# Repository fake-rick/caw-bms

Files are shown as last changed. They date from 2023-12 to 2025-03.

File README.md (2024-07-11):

# CawBMS - 锂电池管理系统

## 🕹 简介

CawBMS 是一套基于 STM32F103 和 BQ76920 的锂电池管理系统。

所有设计资料基于 MIT 协议开源，欢迎大家复刻，可做商业用途。

**请保留 PCB、源码文件中的作者及 Logo 的相关信息。**

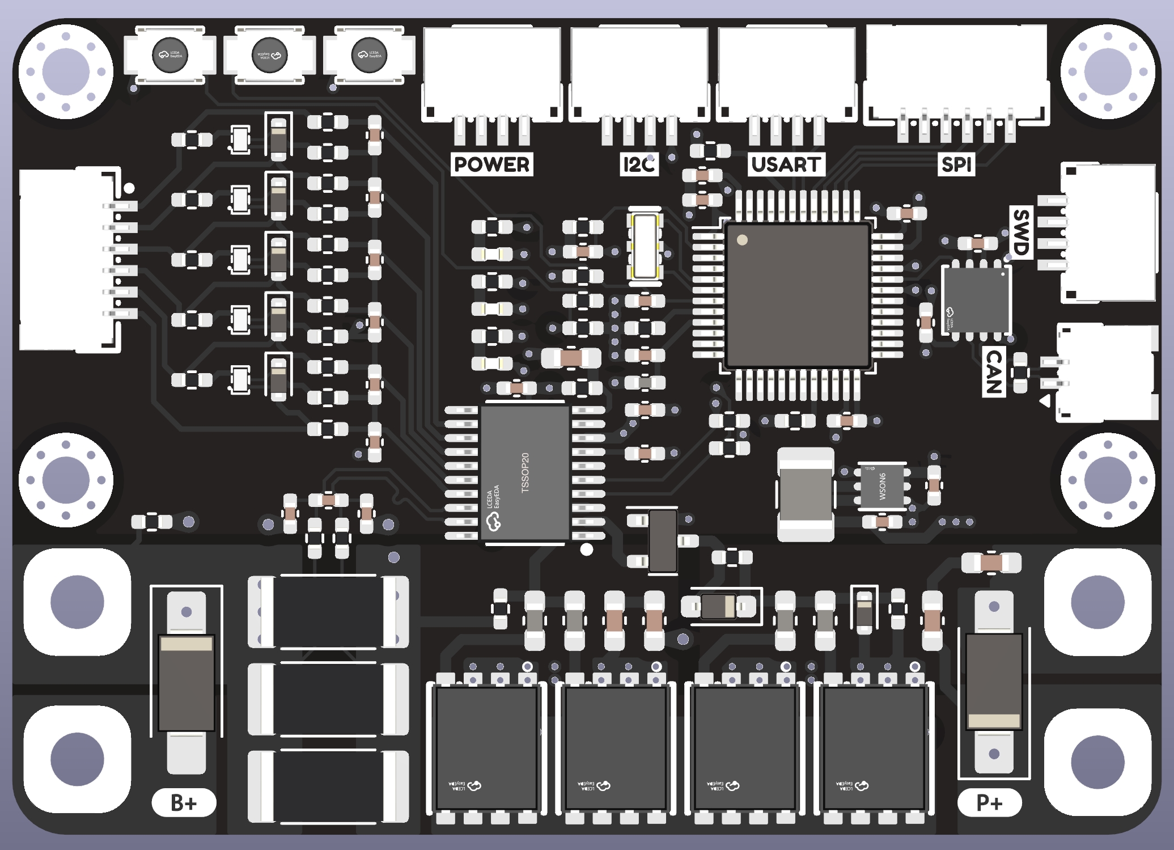
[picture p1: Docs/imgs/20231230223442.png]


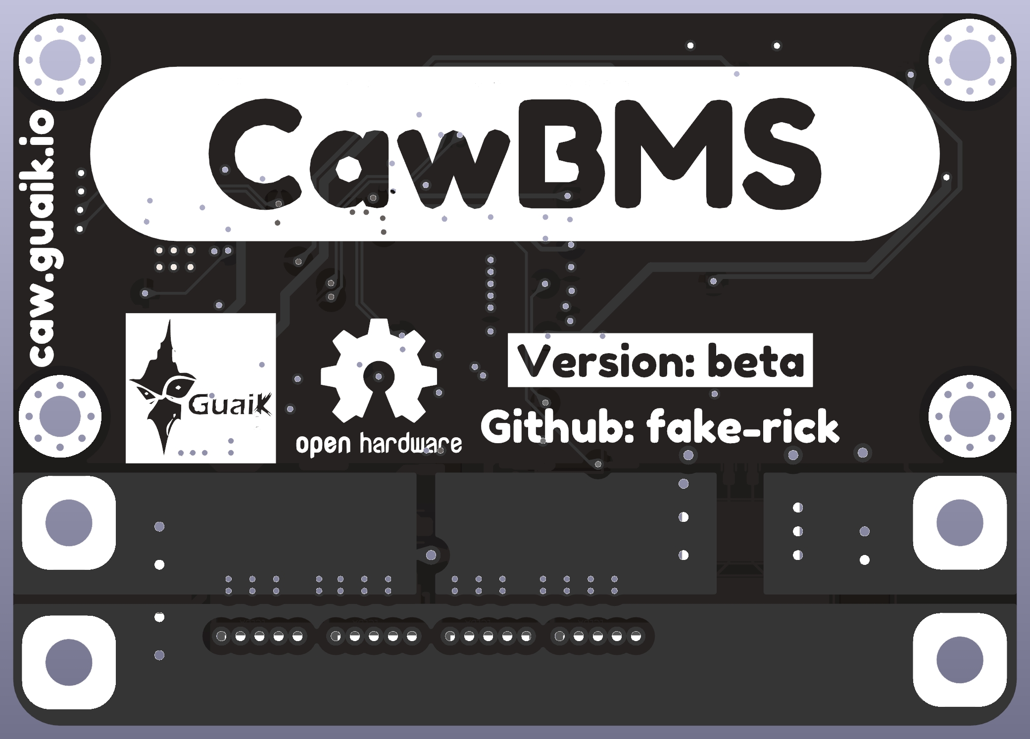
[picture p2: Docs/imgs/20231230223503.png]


## 🛠 功能

| 名称 | 开发状态 | 测试状态 | 名称 | 开发状态 | 测试状态 |
| --- | ---- | ---- | --- | ---- | ---- |
| 开机 | ✔ | ✔ | 欠压保护 | ✔ | ✔ |
| 关机 | ✔ | ✔ | 单节电压监测  | ✔ | ✔ |
| 初始化 | ✔ | ✔ | 电池组电压监测 | ✔ | ✔ |
| 短路保护 | ✔ | ❌ | 电流监测 | ✔ | ✔ |
| 过流保护 | ✔ | ✔ | SOC | ❌ | ❌ |
| 过压保护 | ✔ | ✔ | SOH | ❌ | ❌ |
| 充电被动均衡 | ✔ | ✔ | 上位机 | ❌ | ❌ |

## 📰 目录

- Docs: 项目相关文档

- GUI：上位机软件

- PCB：硬件设计

- Shell：相关外壳设计

- Firmware：固件

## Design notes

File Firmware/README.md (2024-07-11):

### 备注信息

ADCOFFSET 单位 mV
ADCGAIN 单位 uV

Cell 电压计算
V(cell) = GAIN x ADC(cell) + OFFSET

    BQ76920_Init(&afe, &hi2c1);

    HAL_GPIO_TogglePin(LED_A_GPIO_Port, LED_A_Pin);

    BQ76920_Step(&afe);
    BQ76920_UpdateBalanceCell(&afe);

    BQ76920_SYS_STAT_T state;
    BQ76920_SysStat(&afe, &state);
    CAW_LOG_DEBUG("state: %d %d %d %d %d %d %d %d", state.CC_READY, state.RSVD,
                  state.DEVICE_XREADY, state.OVRD_ALERT, state.UV, state.OV,
                  state.SCD, state.OCD);
    CAW_LOG_DEBUG("c1: %f c2: %f c3: %f c4: %f c5 %f", afe.CellVoltage[0],
                  afe.CellVoltage[1], afe.CellVoltage[2], afe.CellVoltage[3],
                  afe.CellVoltage[4]);
    CAW_LOG_DEBUG("VPack: %f, Current: %f", afe.VPack, afe.current);
    BQ76920_SYS_CTRL2_T ctl2;
    BQ76920_SysCtrl2(&afe, &ctl2);

    CAW_LOG_DEBUG("DSG: %d CHG: %d", ctl2.DSG_ON, ctl2.CHG_ON);

    BQ76920_CELLBAL1_T cellbal;
    BQ76920_CellBal1(&afe, &cellbal);
    CAW_LOG_DEBUG("cb1: %d cb2: %d cb3: %d cb4: %d cb5: %d", cellbal.CB1,
                  cellbal.CB2, cellbal.CB3, cellbal.CB4, cellbal.CB5);

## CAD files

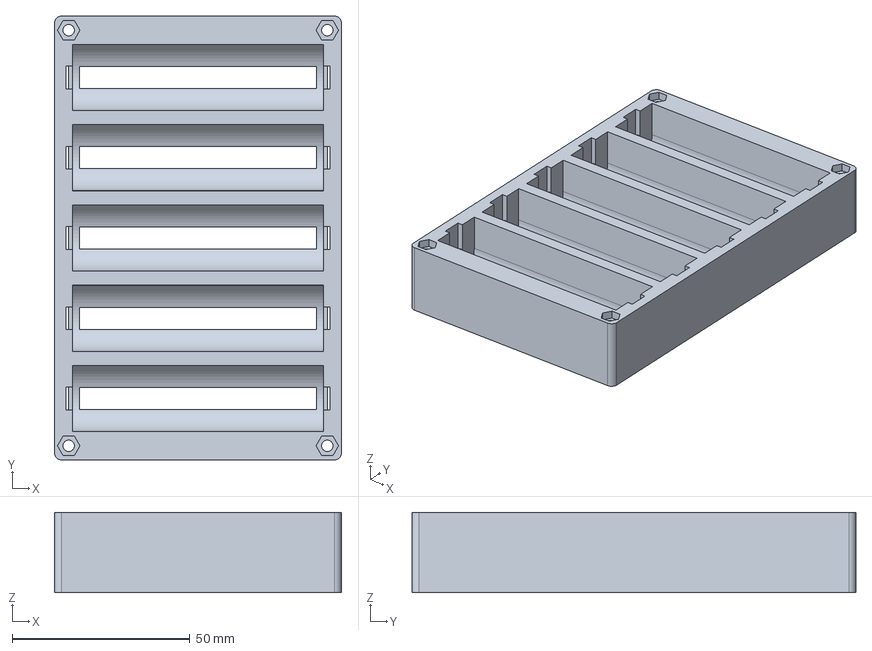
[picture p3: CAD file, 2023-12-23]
Shell/CawBMS-Shell.FCStd
80.8 x 125.0 x 22.6 mm

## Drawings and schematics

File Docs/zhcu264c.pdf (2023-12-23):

# 设计指南：TIDA-00449

# 含 10 节电池的电池组监测、平衡和综合保护、50A 放电参考设

• 专为 36V（10 节锂离子电池或磷酸铁锂电池）而设
计的电池组，可实现 50A 最大持续放电电流
• 通过控制充电或放电 FET 监测电池电压、电池组电
流、电池组温度，以及平衡电池和提供保护
• 在放电过流、放电短路、过压和欠压情况下，均能
提供硬件保护
• 板载超小尺寸、低导通电阻、低 Qg 和 Qgd 的
FemtoFET™ MOSFET，适用于高达每节电池
150mA 的无源平衡电流
• 适合装运的低静态电流、超低功耗状态
• 采用板载主机微控制器来支持实施电池电量监测

TI 设计 TIDA-00449 是一种即时可用并经过测试的硬件
平台，适用于对电动工具含 10 节串联电池的电池组执
行监控、平衡和保护。越来越多的电动工具使用高功率
密度的基于锂离子或磷酸铁锂电池的电池组，我们需要
防止这些电池组因充电或放电不当而发生爆炸。TIDA-
00449 在以持续高电流放电时，也符合电动工具电池组
的热要求。使用 2 层 PCB 实施此参考设计。

Analog Front End

该 TI 参考设计末尾的重要声明表述了授权使用、知识产权问题和其他重要的免责声明和信息。

含 10 节电池的电池组监测、平衡和综合保护、50A 放电参考设计

TIDUAR8 — http://www-s.ti.com/sc/techlit/TIDUAR8
版权 © 2015–2019, Texas Instruments Incorporated

## 1 系统 说明

## 电动工具和园艺工具的电池组较常使用的电池类型为锂离子、锂聚合物或磷酸铁锂电池。这些化学物质的体

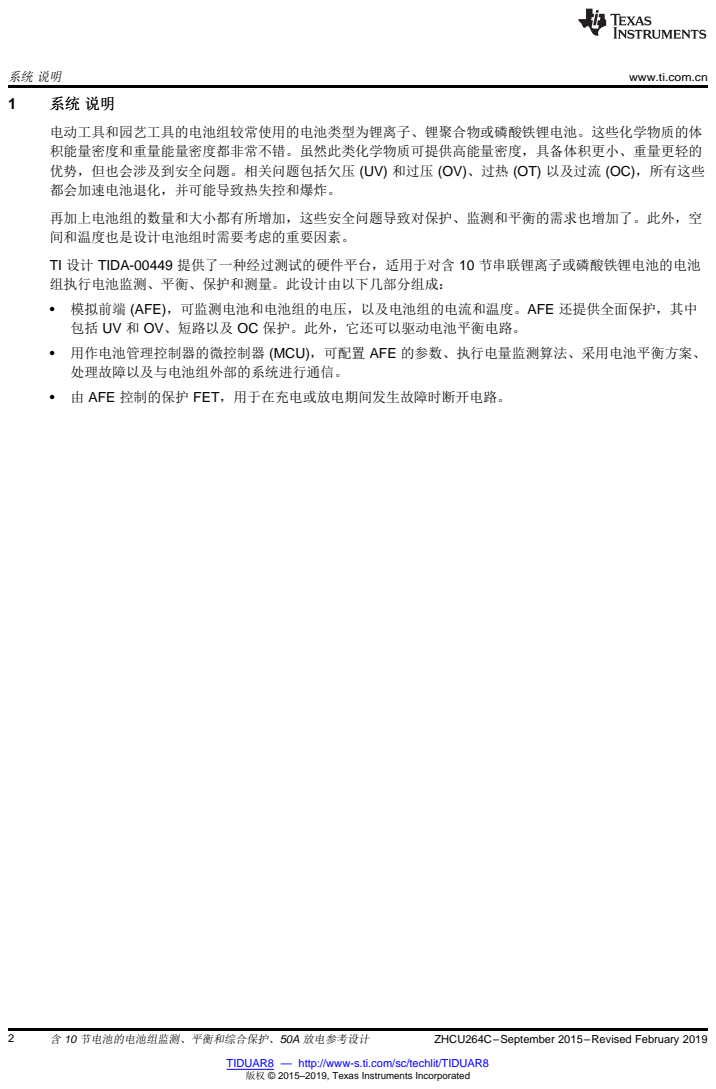
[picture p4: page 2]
www.ti.com.cn; ZHCU264C–September 2015–Revised February 2019

积能量密度和重量能量密度都非常不错。虽然此类化学物质可提供高能量密度，具备体积更小、重量更轻的
优势，但也会涉及到安全问题。相关问题包括欠压 (UV) 和过压 (OV)、过热 (OT) 以及过流 (OC)，所有这些
都会加速电池退化，并可能导致热失控和爆炸。

再加上电池组的数量和大小都有所增加，这些安全问题导致对保护、监测和平衡的需求也增加了。此外，空
间和温度也是设计电池组时需要考虑的重要因素。

TI 设计 TIDA-00449 提供了一种经过测试的硬件平台，适用于对含 10 节串联锂离子或磷酸铁锂电池的电池
组执行电池监测、平衡、保护和测量。此设计由以下几部分组成：
• 模拟前端 (AFE)，可监测电池和电池组的电压，以及电池组的电流和温度。AFE 还提供全面保护，其中
包括 UV 和 OV、短路以及 OC 保护。此外，它还可以驱动电池平衡电路。
• 用作电池管理控制器的微控制器 (MCU)，可配置 AFE 的参数、执行电量监测算法、采用电池平衡方案、
处理故障以及与电池组外部的系统进行通信。
• 由 AFE 控制的保护 FET，用于在充电或放电期间发生故障时断开电路。

## 2 设计 特性

### TIDA-00449 使用 10S3P 电池组（30-42V，12.6Ah）。

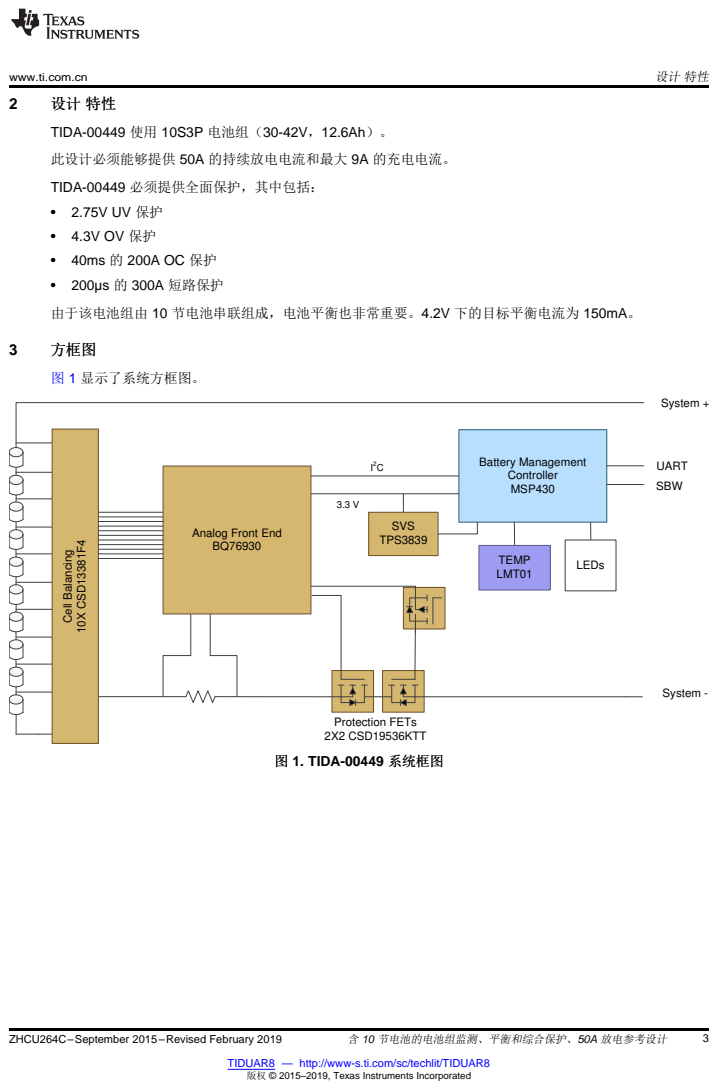
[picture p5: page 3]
LEDs; SVS TPS3839; Battery Management Controller MSP430; System +; System -; UART; SBW; Cell Balancing; 10X CSD13381F4; Protection FETs 2X2 CSD19536KTT; TEMP LMT01; www.ti.com.cn; 3 方框图; 图 1 显示了系统方框图。; 图 1. TIDA-00449 系统框图

此设计必须能够提供 50A 的持续放电电流和最大 9A 的充电电流。

TIDA-00449 必须提供全面保护，其中包括：
• 200µs 的 300A 短路保护

由于该电池组由 10 节电池串联组成，电池平衡也非常重要。4.2V 下的目标平衡电流为 150mA。

Analog Front End

SENSE _ OCD _MAX

100 mV R | 0.5 m
200 A
= | = | W SENSE _ SCD _MAX
200 mV R | 0.667 m
300 A
= | = | W

THRESHOLD
SENSE
LIM

V
R
I

=

电路设计和组件选择 | www.ti.com.cn

## 4 电路设计和组件选择

## 4.1 AFE

### 4.1.1 器件选择

## bq769x0 系列的强大 AFE 设备可用作下一代高功率系统（如电动工具）的完整电池组监测和保护解决方案 的一部分。bq769x0 在设计时充分考虑了低功耗要求，不仅可通过启用/禁用集成电路 (IC) 中的子块来控制 整个芯片的电流消耗，而且还可以利用运输模式将电池组轻松切换至超低功耗状态。

## bq76930 最高支持 10 节串联电池或典型的 36V 电池组。该 AFE 可以测量各种电池化学物质，包括锂离 子、磷酸铁锂等。通过 I

## 2C，主机控制器可以使用 bq76930 来执行多种电池组管理功能，例如监测（电池电 压、电池组电流、电池组温度）、保护（控制充电/放电 FET）以及平衡功能。集成式 ADC 可实现对关键系 统参数的纯数字读取，这些参数的校准在 TI 制造过程中进行处理。

### 4.1.2 电流感测

## 在设计电池组监测、平衡和保护电路时，首先要做的工作之一是选择传感电阻器。为此，请考虑短路电流限 制 (SCD) 和过流限制 (OCD)，以及 AFE 使用的电压阈值设置。请注意，在电池管理控制器中可以进一步实 施其他电流限制阈值，以实现更详尽的保护方案（请参见节 4.2.3.1）。

### 此设计的目标是：300A 左右的 SCD 持续 200μs，200A 左右的 OCD 持续 40ms。您可以在 bq76930 产品

说明书 (SLUSBK2) (http://www.ti.com/lit/pdf/SLUSBK2) 的第 36 页和 37 页查看电压阈值设置。SCD 和 OCD 的电压阈值最大值分别为 200mV

## 和 100mV。根据欧姆定律，SCD 的传感电阻器最大值为 0.67mΩ，OCD 的传感电阻器最大值为 0.5mΩ， 如公式 2 和公式 3 中所示。

(1)

因此，

(2)

(3)

## 所选的 RSENSE 等于 0.5mΩ。

## 为了采用 300A 的 0.5mΩ 传感电阻器，电压阈值现已经过重新计算。重复利用公式 2 可为 SCD 提供

150mV 的电压阈值。bq76930 产品说明书 (SLUSBK2) (http://www.ti.com/lit/pdf/SLUSBK2) 第 36 页的表格中未列出 150mV，但列出了

### 155mV；因此，采用 155mV 为 SCD 提供 310A 的电流。

## 此应用的最大持续电流为 50A，这意味着使用 0.5mΩ 的传感电阻器时，会消耗 1.25W 功率。

## 考虑到所有这些因素（包括功耗方面的一些优势），可以并联使用三个 1.5mΩ 的 2512 1% 2W 电阻器装 置。使用 SCD 和 OCD 比较器持续监测传感电阻器的电压，从而提供保护。该电压还会被馈送至 16 位集成 式 ADC（通常称为库仑计数器 (CC)），该 ADC 会测量电流传感电阻器上累积的电荷。

www.ti.com.cn | 电路设计和组件选择

### 4.1.3 保护 FET

## 现在，我们已选择好传感电阻器，下一步是设计保护 FET。

## 这些 FET 用于在发生故障时断开电路。表 1 显示了放电 FET (DSG) 和充电 FET (CHG) 何时设断开状态。

## 对于这两个 FET，采用单独控制的方式，即使发生某种故障，也可以安全地使用电池组。例如，如果电池组 已完全放电，则会触发 UV 故障，从而断开 DSG FET，防止放电电流进一步流动。与此同时，CHG FET 保 持闭合状态，允许所施加的充电电流流动。

## 表 1. CHG 和 DSG 对不同事件的响应

事件 | CHG FET 断开 | DSG FET 断开
OV 故障 | 是 | —
UV 故障 | — | 是
OCD 故障 | — | 是
SCD 故障 | — | 是
警报覆盖 | 是 | 是
已设置 DEVICE_XREADY | 是 | 是
从正常模式进入运输模式 | 是 | 是

## 在不需要保护 FET 的情况下，TIDA-00449 为用户提供了两个焊盘以绕过保护 FET。7.4 节 中提供了更多详 细信息。

### 4.1.3.1 FET 选择

## 要选择 FET，请考虑以下四个主要参数：电压、电流、热性能和 FET 的开关时间。

## FET 的额定电压必须高于每节串联电池约 5V 的直流电压，以及每节串联电池的 10V 瞬态电压。在本设计 中，装置使用了 10 节电池串联，这意味着 FET（Q13、Q14、Q15 和 Q16）的额定电压应高于 50V 直流 电压和 100V 瞬态电压。

### TIDA-00449 的电流要求如下：75A 持续电流，300A 电流持续 400μs，200A 瞬态电流持续 40ms。

## 在热性能方面，要优先考虑使用尽可能低的 RDSON 值，以便最大程度地减少这些 FET 的功耗。此外，封装 也是一项关键因素，因为它应该能够承受热损耗并有效地消散 PCB 或散热器的热损耗。

## 最后，断开和闭合 FET 所需的时间也至关重要。这主要受 BQ76930 AFE 中栅极驱动器的强度和 FET 的栅 极电荷的影响（请参见节 4.1.3.2，了解更多详细信息）。

## 本设计将所有这些参数均考虑在内，并联使用了两个 CSD19536KTT。CSD19536KTT 是一个 100V、

### 2mΩ、超低 Qg 和 Qgd 的 D

### 2PAK (TO-263) NexFET™ 功率 MOSFET。

电路设计和组件选择 | www.ti.com.cn

### 4.1.3.2 FET 驱动器
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

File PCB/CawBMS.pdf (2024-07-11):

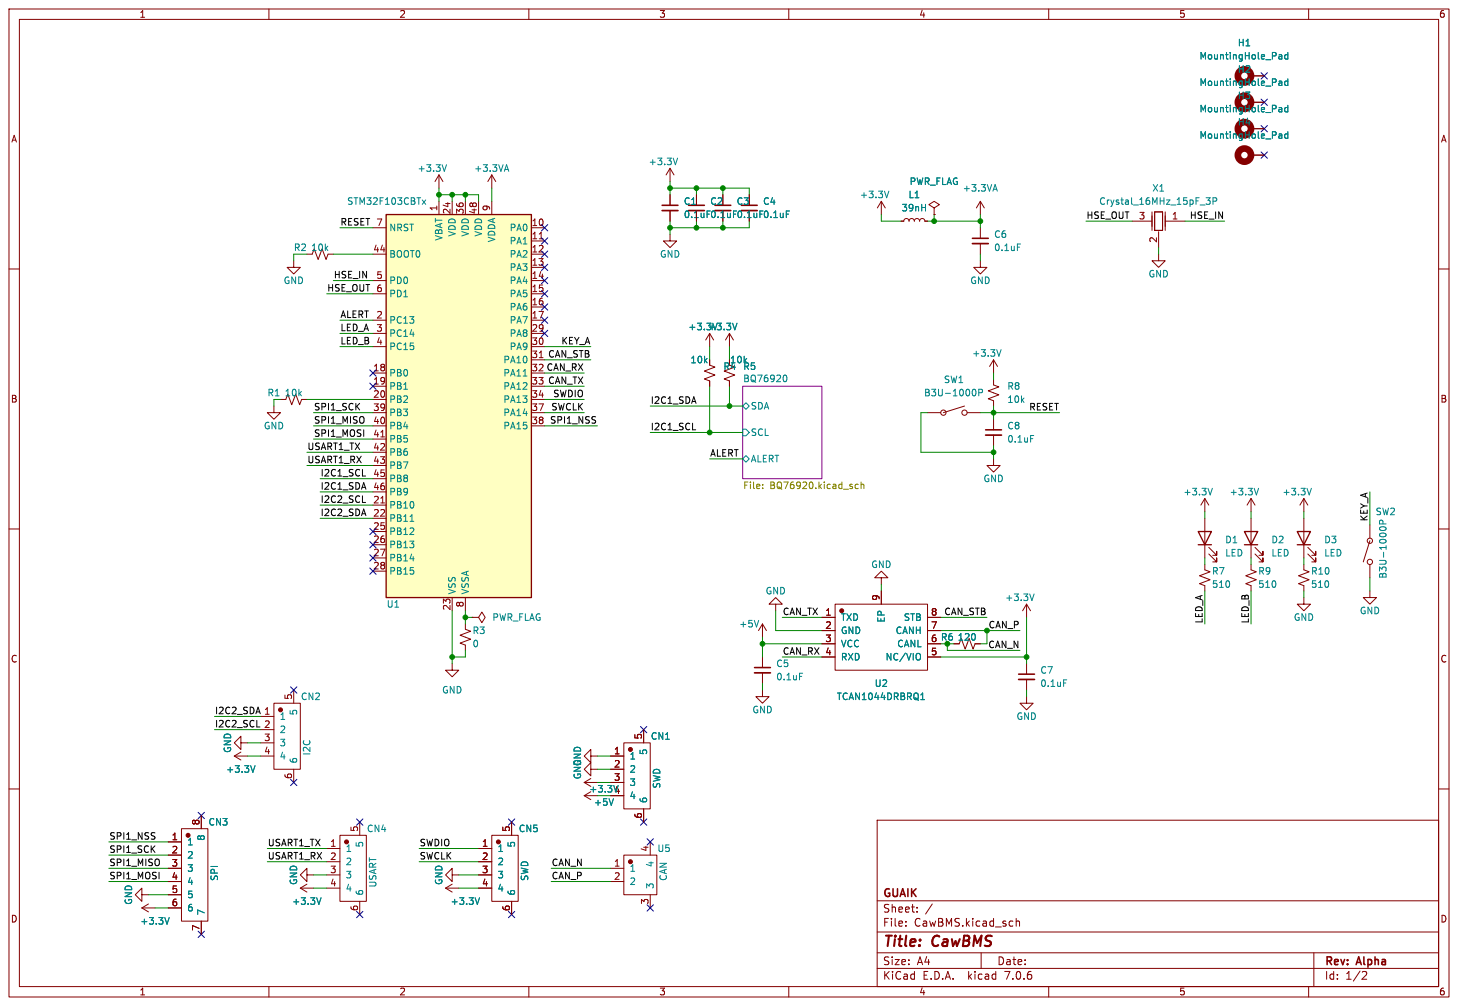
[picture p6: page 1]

1 PA0 10 PA1 11 PA2 12 PA3 13 PA4 14 PA5 15 PA6 16 PA7 17 PB0 18 PB1 19 PC13 2 PB2 20 PB10 21 PB11 22 VSS 23 VDD 24 PB12 25 PB13 26 PB14 27 PB15 28 PA8 29 PC14 3 PA9 30 PA10 31 PA11 32 PA12 33 PA13 34 VDD 36 PA14 37 PA15 38 PB3 39 PC15 4 PB4 40 PB5 41 PB6 42 PB7 43 BOOT0 44 PB8 45 PB9 46 VDD 48 PD0 5 PD1 6 NRST 7 VSSA

File: CawBMS.kicad_sch Sheet: / GUAIK

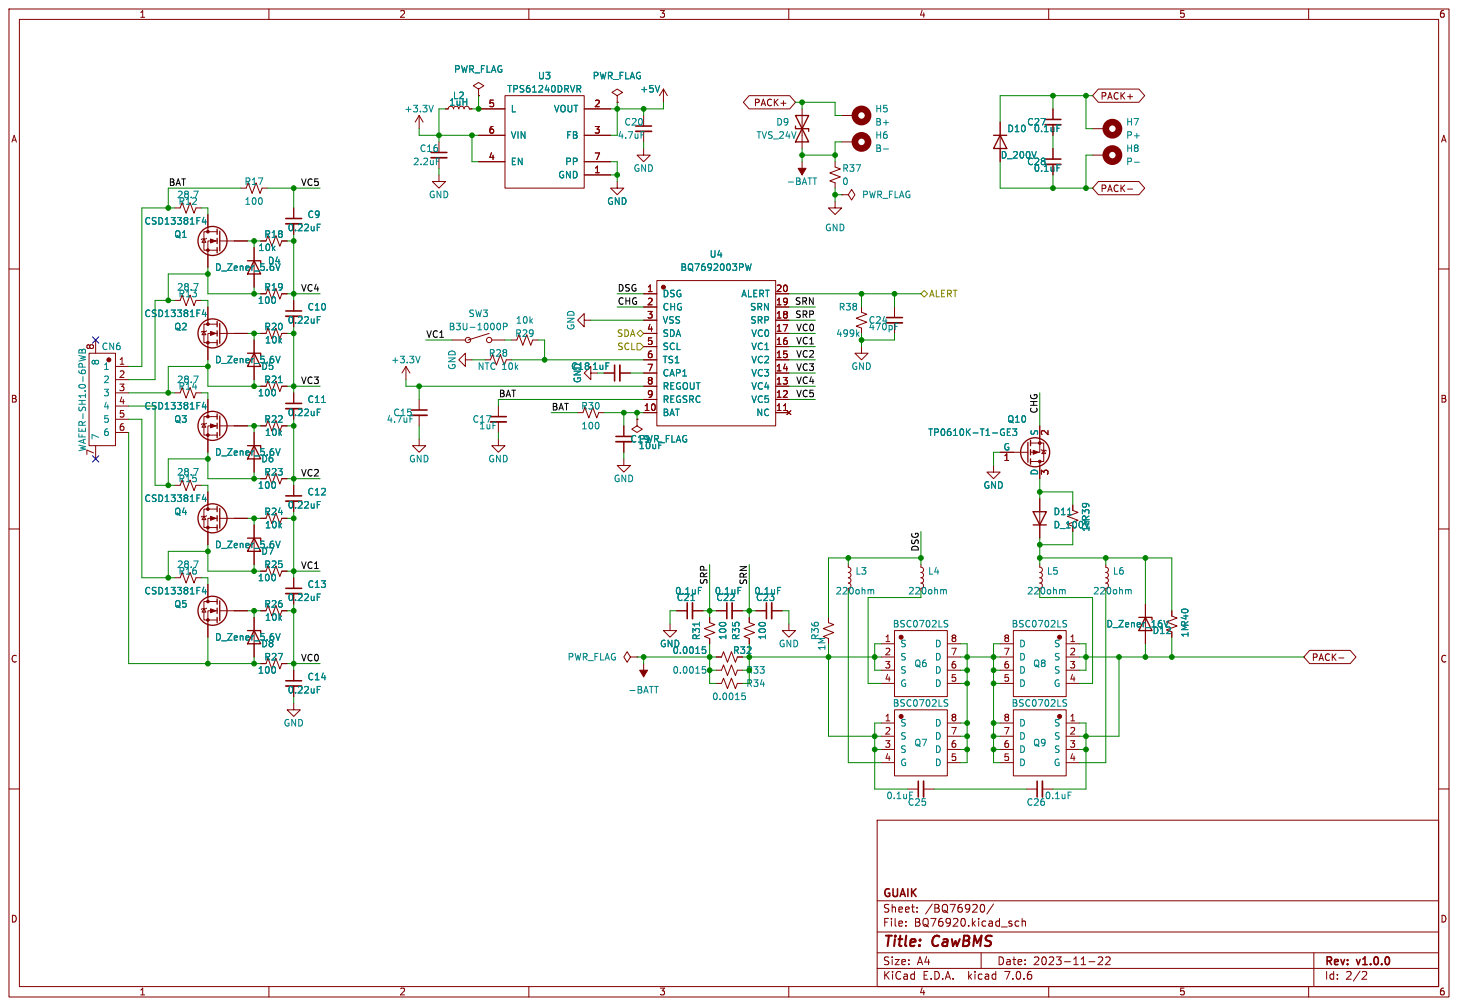
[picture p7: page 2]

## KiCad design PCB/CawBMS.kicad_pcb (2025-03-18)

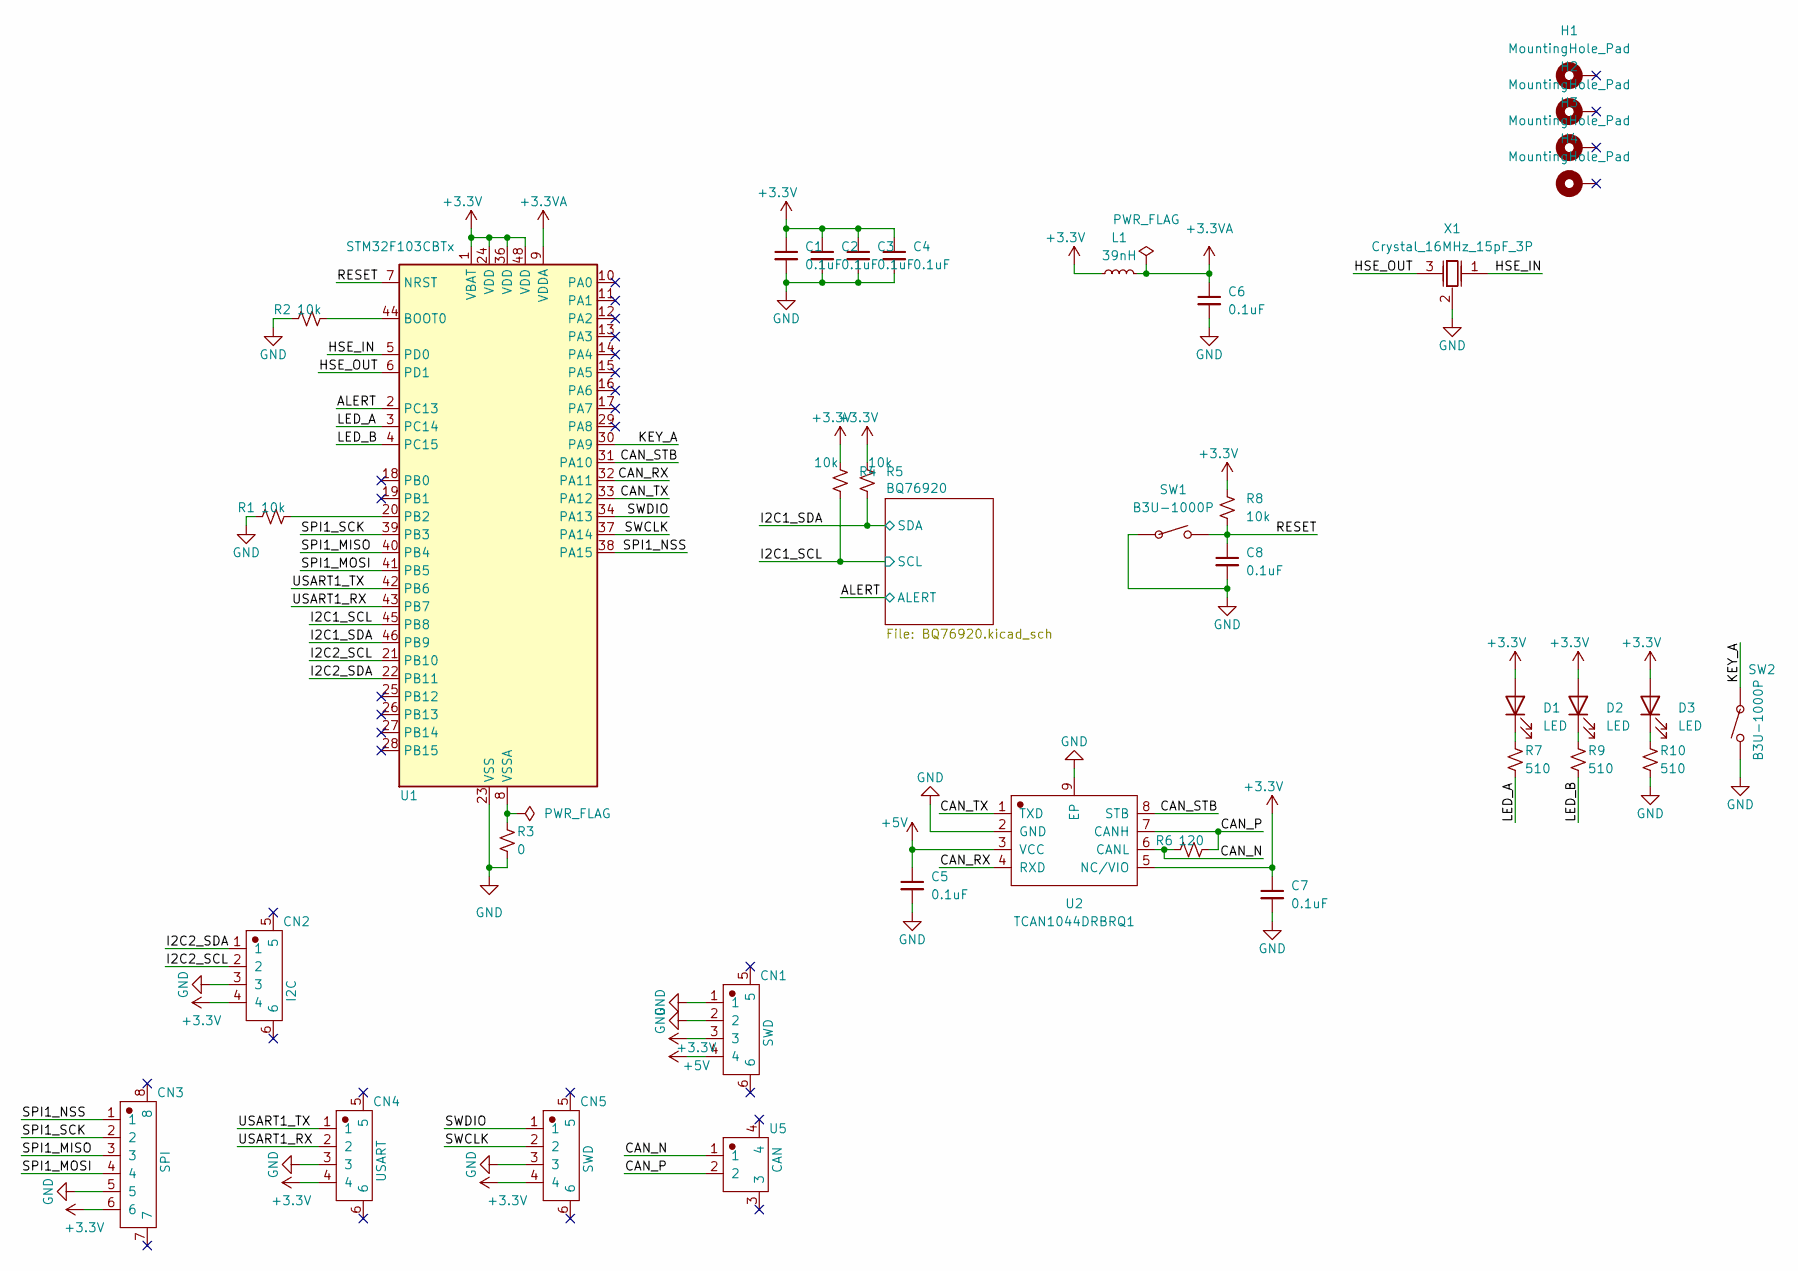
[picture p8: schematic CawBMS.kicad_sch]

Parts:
C1, C2, C3, C4, C5, C6, C7, C8: 0.1uF; C_0402_1005Metric_Pad0.74x0.62mm_HandSolder
CN1, CN5: SWD; CONN-SMD_4P-P1.00_WAFER-SH1.0-4PWB
CN2: I2C; CONN-SMD_4P-P1.00_WAFER-SH1.0-4PWB
CN3: SPI; CONN-SMD_6P-P1.00_XUNPU_WAFER-SH1.0-6PWB
CN4: USART; CONN-SMD_4P-P1.00_WAFER-SH1.0-4PWB
D1, D2, D3: LED; LED_0402_1005Metric_Pad0.77x0.64mm_HandSolder
H1, H2, H3, H4: MountingHole_Pad; MountingHole_2.2mm_M2_Pad_Via
L1: 39nH; L_0402_1005Metric_Pad0.77x0.64mm_HandSolder
R1, R2, R4, R5, R8: 10k; R_0402_1005Metric_Pad0.72x0.64mm_HandSolder
R3: 0; R_0402_1005Metric_Pad0.72x0.64mm_HandSolder
R6: 120; R_0402_1005Metric_Pad0.72x0.64mm_HandSolder
R7, R9, R10: 510; R_0402_1005Metric_Pad0.72x0.64mm_HandSolder
SW1, SW2: B3U-1000P; JLC Part Number C231329
U1: STM32F103CBTx; LQFP-48_7x7mm_P0.5mm
U2: TCAN1044DRBRQ1; TCAN1044DRBRQ1_DFN-8_L3.0-W3.0-P0.65-TL-EP2.4
U5: CAN; CONN-SMD_2P-P1.00_XUNPU_WAFER-SH1.0-2PWB
X1: Crystal_16MHz_15pF_3P; Crystal_SMD3213-3P; JLC Part Number C341521

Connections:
+3.3V: C1.1, C2.1, C3.1, C4.1, C7.1, CN1.3, CN2.4, CN3.6, CN4.4, CN5.4, D1.2 (A), D2.2 (A), D3.2 (A), L1.1, R4.1, R5.1, R8.1, U1.1 (VBAT), U1.24 (VDD), U1.36 (VDD), U1.48 (VDD), U2.5 (NC/VIO); also elsewhere on the board
+3.3VA: C6.1, L1.2, U1.9 (VDDA)
+5V: C5.1, CN1.4, U2.3 (VCC); also elsewhere on the board
/ALERT: U1.2 (PC13); also elsewhere on the board
/CAN_N: R6.1, U2.6 (CANL), U5.1
/CAN_P: R6.2, U2.7 (CANH), U5.2
/CAN_RX: U1.32 (PA11), U2.4 (RXD)
/CAN_STB: U1.31 (PA10), U2.8 (STB)
/CAN_TX: U1.33 (PA12), U2.1 (TXD)
/HSE_IN: U1.5 (PD0), X1.1 (OSC1)
/HSE_OUT: U1.6 (PD1), X1.3 (OSC2)
/I2C1_SCL: R4.2, U1.45 (PB8); also elsewhere on the board
/I2C1_SDA: R5.2, U1.46 (PB9); also elsewhere on the board
/I2C2_SCL: CN2.2, U1.21 (PB10)
/I2C2_SDA: CN2.1, U1.22 (PB11)
/KEY_A: SW2.1, U1.30 (PA9)
/LED_A: R7.2, U1.3 (PC14)
/LED_B: R9.2, U1.4 (PC15)
/RESET: C8.1, R8.2, SW1.2, U1.7 (NRST)
/SPI1_MISO: CN3.3, U1.40 (PB4)
/SPI1_MOSI: CN3.4, U1.41 (PB5)
/SPI1_NSS: CN3.1, U1.38 (PA15)
/SPI1_SCK: CN3.2, U1.39 (PB3)
/SWCLK: CN5.2, U1.37 (PA14)
/SWDIO: CN5.1, U1.34 (PA13)
/USART1_RX: CN4.2, U1.43 (PB7)
/USART1_TX: CN4.1, U1.42 (PB6)
GND: C1.2, C2.2, C3.2, C4.2, C5.2, C6.2, C7.2, C8.2, CN1.1, CN1.2, CN2.3, CN3.5, CN4.3, CN5.3, R1.1, R2.1, R3.2, R10.2, SW1.1, SW2.2, U1.23 (VSS), U1.35 (VSS), U1.47 (VSS), U2.2 (GND), U2.9 (EP), X1.2 (GND); also elsewhere on the board
unnamed: D1.1 (K), R7.1
unnamed: D2.1 (K), R9.1
unnamed: D3.1 (K), R10.1
unnamed: R2.2, U1.44 (BOOT0)
unnamed: R1.2, U1.20 (PB2)
unnamed: R3.1, U1.8 (VSSA)

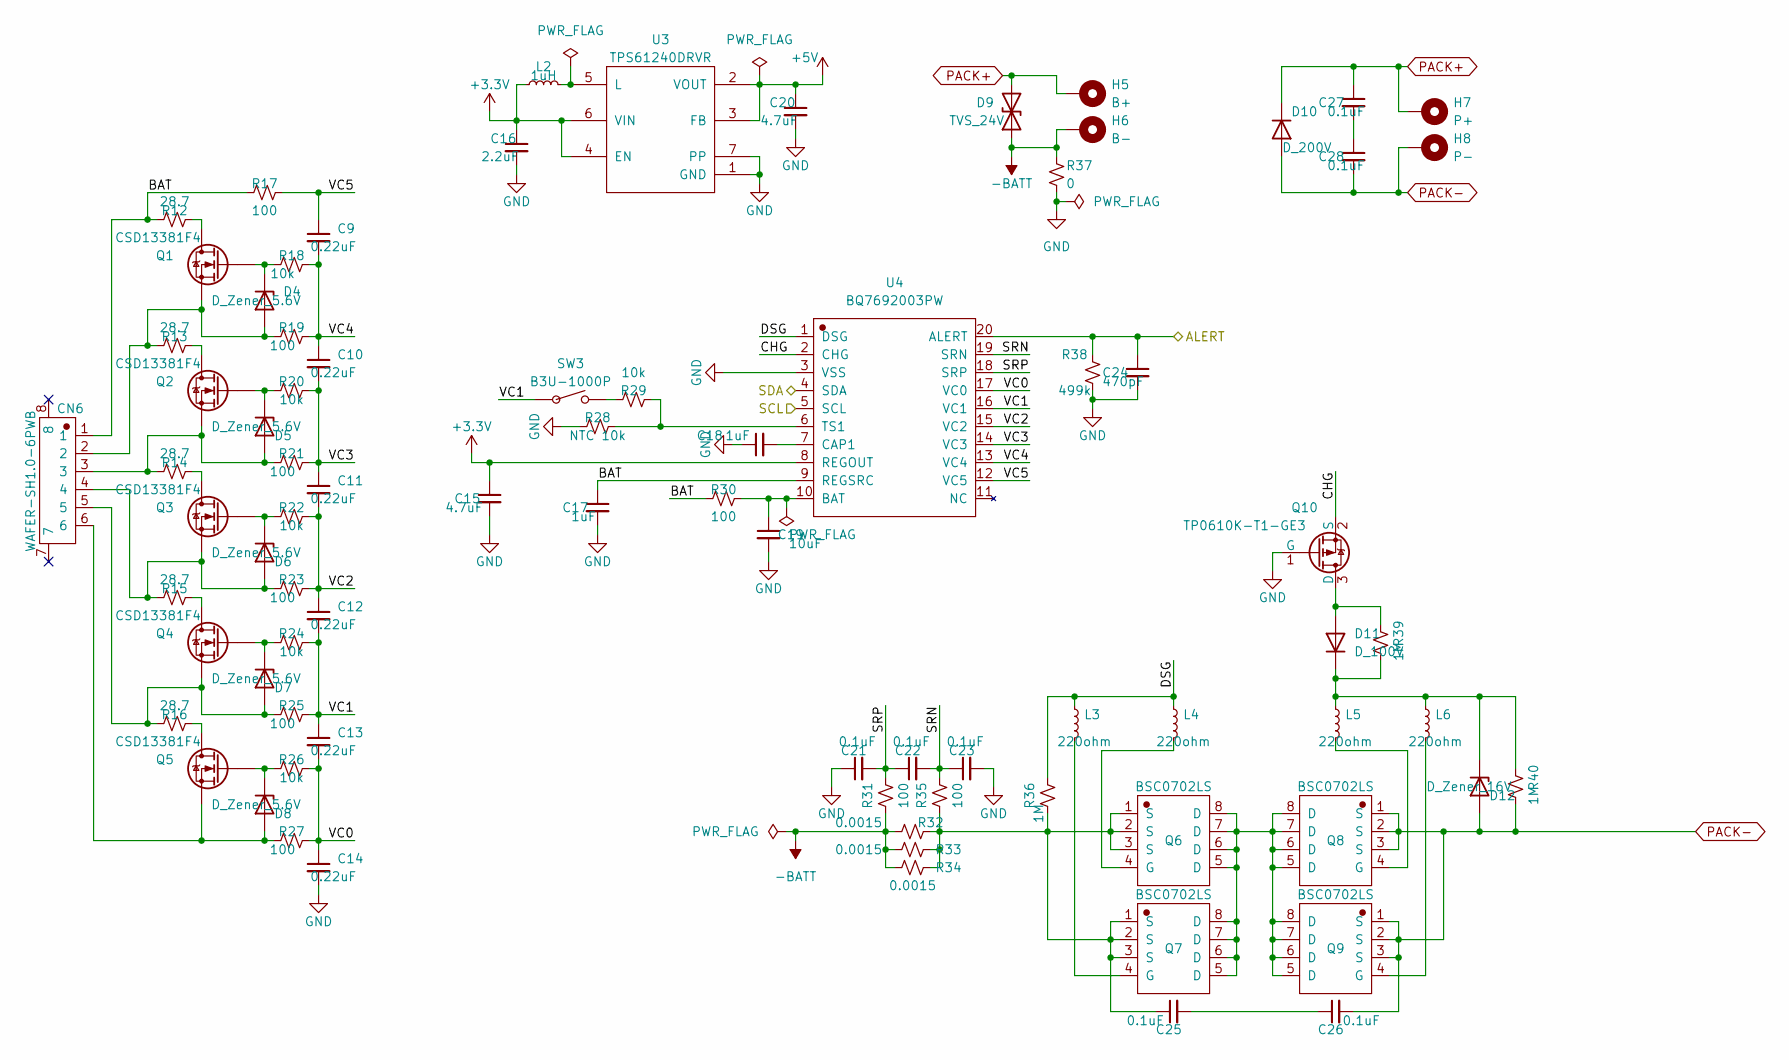
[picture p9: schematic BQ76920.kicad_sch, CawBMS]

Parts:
C9, C10, C11, C12, C13, C14: 0.22uF; C_0402_1005Metric_Pad0.74x0.62mm_HandSolder
C15, C20: 4.7uF; C_0402_1005Metric_Pad0.74x0.62mm_HandSolder
C16: 2.2uF; C_0402_1005Metric_Pad0.74x0.62mm_HandSolder
C17, C18: 1uF; C_0402_1005Metric_Pad0.74x0.62mm_HandSolder
C19: 10uF; C_0603_1608Metric_Pad1.08x0.95mm_HandSolder
C21, C22, C23: 0.1uF; C_0402_1005Metric_Pad0.74x0.62mm_HandSolder
C24: 470pF; C_0402_1005Metric_Pad0.74x0.62mm_HandSolder
C25, C26, C27, C28: 0.1uF; C_0603_1608Metric_Pad1.08x0.95mm_HandSolder
CN6: WAFER-SH1.0-6PWB; CONN-SMD_6P-P1.00_XUNPU_WAFER-SH1.0-6PWB
D4, D5, D6, D7, D8: D_Zener_5.6V; D_SOD-523
D9: TVS_24V; D_SMA_Handsoldering
D10: D_200V; D_SMA_Handsoldering
D11: D_100V; D_SOD-323_HandSoldering
D12: D_Zener_16V; D_SOD-523
H5: B+; POWER_PAD
H6: B-; POWER_PAD
H7: P+; POWER_PAD
H8: P-; POWER_PAD
L2: 1uH; L_1210_3225Metric_Pad1.42x2.65mm_HandSolder
L3, L4, L5, L6: 220ohm; L_0603_1608Metric_Pad1.05x0.95mm_HandSolder
Q1, Q2, Q3, Q4, Q5: CSD13381F4; CSD13381F4_PICOSTAR-3_L1.0-W0.6-P0.40-S0.65-BL-1
Q6, Q7, Q8, Q9: BSC0702LS; BSC0702LS_PG-TDSON-8_L5.0-W6.0-P1.27-BL-EP
Q10: TP0610K-T1-GE3; SOT-23
R12, R13, R14, R15, R16: 28.7; R_0402_1005Metric_Pad0.72x0.64mm_HandSolder
R17, R19, R21, R23, R25, R27, R30, R31, R35: 100; R_0402_1005Metric_Pad0.72x0.64mm_HandSolder
R18, R20, R22, R24, R26, R29: 10k; R_0402_1005Metric_Pad0.72x0.64mm_HandSolder
R28: NTC 10k; R_0402_1005Metric_Pad0.72x0.64mm_HandSolder
R32, R33, R34: 0.0015; R_2512_6332Metric_Pad1.40x3.35mm_HandSolder
R36, R39, R40: 1M; R_0402_1005Metric_Pad0.72x0.64mm_HandSolder
R37: 0; R_0402_1005Metric_Pad0.72x0.64mm_HandSolder
R38: 499k; R_0402_1005Metric_Pad0.72x0.64mm_HandSolder
SW3: B3U-1000P; JLC Part Number C231329
U3: TPS61240DRVR; TPS61240DRVR_WSON-6_L2.0-W2.0-P0.65-TL-EP
U4: BQ7692003PW; BQ7692003PW_TSSOP-20_L6.5-W4.4-P0.65-LS6.4-BL

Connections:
+3.3V: C15.1, C16.1, L2.1, U3.4 (EN), U3.6 (VIN), U4.8 (REGOUT); also elsewhere on the board
+5V: C20.1, U3.2 (VOUT), U3.3 (FB); also elsewhere on the board
-BATT: D9.1 (A1), H6.1, R31.1, R32.1, R33.1, R34.1, R37.1
/ALERT: C24.1, R38.2, U4.20 (ALERT); also elsewhere on the board
/BQ76920/BAT: C17.1, CN6.1, R12.1, R17.1, R30.1, U4.9 (REGSRC)
/BQ76920/CHG: Q10.2 (S), U4.2 (CHG)
/BQ76920/DSG: L3.1, L4.1, R36.2, U4.1 (DSG)
/BQ76920/SRN: C22.2, C23.1, R35.2, U4.19 (SRN)
/BQ76920/SRP: C21.2, C22.1, R31.2, U4.18 (SRP)
/BQ76920/VC0: C13.2, C14.1, R26.2, R27.2, U4.17 (VC0)
/BQ76920/VC1: C12.2, C13.1, R24.2, R25.2, SW3.1, U4.16 (VC1)
/BQ76920/VC2: C11.2, C12.1, R22.2, R23.2, U4.15 (VC2)
/BQ76920/VC3: C10.2, C11.1, R20.2, R21.2, U4.14 (VC3)
/BQ76920/VC4: C9.2, C10.1, R18.2, R19.2, U4.13 (VC4)
/BQ76920/VC5: C9.1, R17.2, U4.12 (VC5)
/I2C1_SCL: U4.5 (SCL); also elsewhere on the board
/I2C1_SDA: U4.4 (SDA); also elsewhere on the board
GND: C14.2, C15.2, C16.2, C17.2, C18.1, C19.2, C20.2, C21.1, C23.2, C24.2, Q10.1 (G), R28.1, R37.2, R38.1, U3.1 (GND), U3.7 (PP), U4.3 (VSS); also elsewhere on the board
unnamed: C25.1, Q6.1 (S), Q6.2 (S), Q6.3 (S), Q7.1 (S), Q7.2 (S), Q7.3 (S), R32.2, R33.2, R34.2, R35.1, R36.1
unnamed: C25.2, C26.1
unnamed: C27.2, C28.1
unnamed: CN6.2, D4.2 (A), Q1.2 (S), R13.1, R19.1
unnamed: D4.1 (K), Q1.1 (G), R18.1
unnamed: CN6.3, D5.2 (A), Q2.2 (S), R14.1, R21.1
unnamed: D5.1 (K), Q2.1 (G), R20.1
unnamed: CN6.4, D6.2 (A), Q3.2 (S), R15.1, R23.1
unnamed: D6.1 (K), Q3.1 (G), R22.1
unnamed: CN6.5, D7.2 (A), Q4.2 (S), R16.1, R25.1
unnamed: D7.1 (K), Q4.1 (G), R24.1
unnamed: CN6.6, D8.2 (A), Q5.2 (S), R27.1
unnamed: D8.1 (K), Q5.1 (G), R26.1
unnamed: D11.2 (A), Q10.3 (D), R39.2
unnamed: D11.1 (K), D12.1 (K), L5.1, L6.1, R39.1, R40.2
unnamed: Q1.3 (D), R12.2
unnamed: Q2.3 (D), R13.2
unnamed: Q3.3 (D), R14.2
unnamed: Q4.3 (D), R15.2
unnamed: Q5.3 (D), R16.2
unnamed: Q6.5 (D), Q6.6 (D), Q6.7 (D), Q6.8 (D), Q7.5 (D), Q7.6 (D), Q7.7 (D), Q7.8 (D), Q8.5 (D), Q8.6 (D), Q8.7 (D), Q8.8 (D), Q9.5 (D), Q9.6 (D), Q9.7 (D), Q9.8 (D)
unnamed: L4.2, Q6.4 (G)
unnamed: L3.2, Q7.4 (G)
unnamed: L5.2, Q8.4 (G)
unnamed: L6.2, Q9.4 (G)
unnamed: R29.1, SW3.2
unnamed: L2.2, U3.5 (L)
unnamed: C19.1, R30.2, U4.10 (BAT)
unnamed: C18.2, U4.7 (CAP1)
unnamed: R28.2, R29.2, U4.6 (TS1)
PACK+: C27.1, D9.2 (A2), D10.1 (K), H5.1, H7.1
PACK-: C26.2, C28.2, D10.2 (A), D12.2 (A), H8.1, Q8.1 (S), Q8.2 (S), Q8.3 (S), Q9.1 (S), Q9.2 (S), Q9.3 (S), R40.1

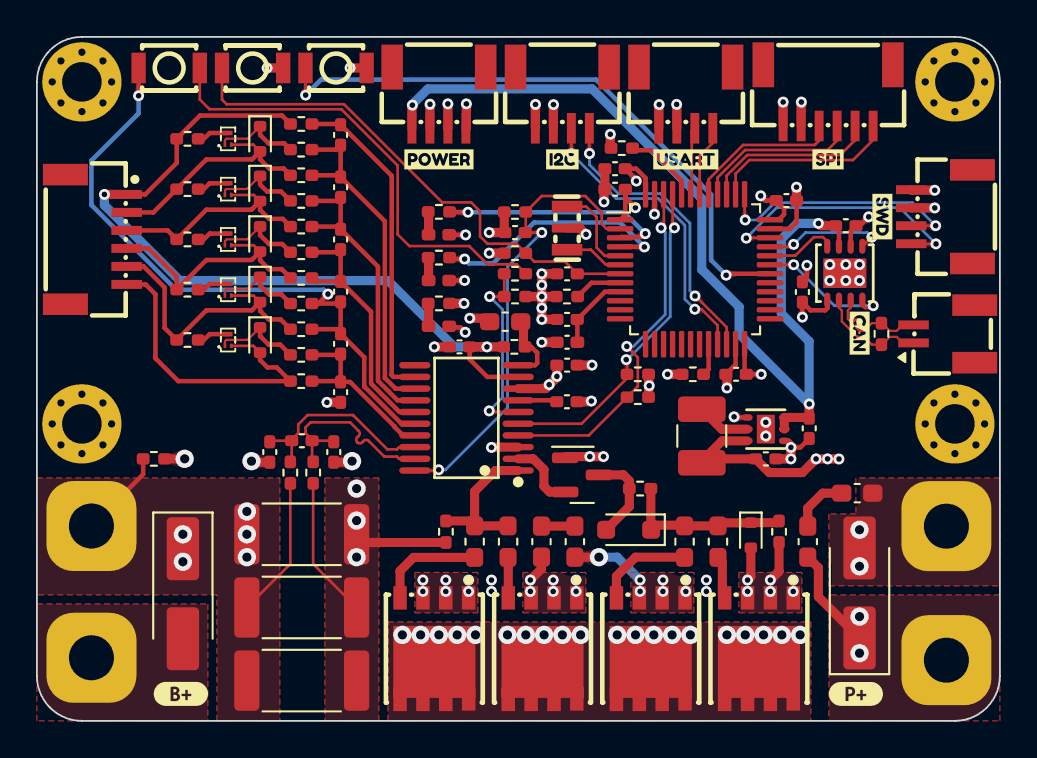
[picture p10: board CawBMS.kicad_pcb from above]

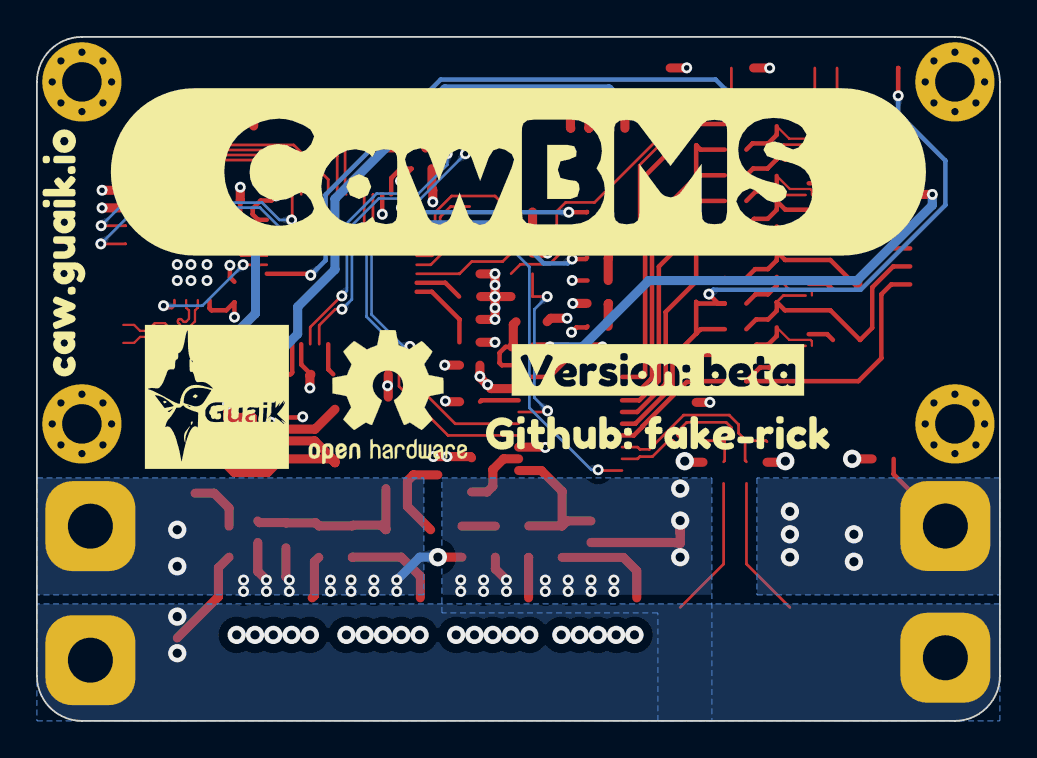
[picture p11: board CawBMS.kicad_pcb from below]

Board: 4 copper layers, 53.5 x 38.0 mm, 130 parts (4 on the bottom side), 78 nets.

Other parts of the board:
kibuzzard-658FE662: G***; kibuzzard-658FE662
kibuzzard-658FE679: G***; kibuzzard-658FE679
kibuzzard-6577EBAB: G***; kibuzzard-6577EBAB
kibuzzard-6577EBC9: G***; kibuzzard-6577EBC9
kibuzzard-6577EC0F: G***; kibuzzard-6577EC0F
kibuzzard-6577EC47: G***; kibuzzard-6577EC47
kibuzzard-6577F8B5: G***; kibuzzard-6577F8B5
kibuzzard-6577F12B: G***; kibuzzard-6577F12B
kibuzzard-6577F182: G***; kibuzzard-6577F182
kibuzzard-6582907D: G***; kibuzzard-6582907D
kibuzzard-65829086: G***; kibuzzard-65829086
kibuzzard-65902364: G***; kibuzzard-65902364

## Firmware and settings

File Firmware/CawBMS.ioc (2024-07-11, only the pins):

Mcu.UserName=STM32F103CBTx
PA10.GPIO_Label=CAN_STB
PA10.Signal=GPIO_Output
PA11.Signal=CAN_RX
PA12.Signal=CAN_TX
PA13.Signal=SYS_JTMS-SWDIO
PA14.Signal=SYS_JTCK-SWCLK
PA15.GPIO_Label=SPI1_NSS
PA15.Signal=GPIO_Output
PA9.GPIO_Label=KEY_A
PA9.Signal=GPXTI9
PB10.Signal=I2C2_SCL
PB11.Signal=I2C2_SDA
PB3.Signal=SPI1_SCK
PB4.GPIO_Label=OLED_DC
PB4.Signal=GPIO_Output
PB5.Signal=SPI1_MOSI
PB6.Signal=USART1_TX
PB7.Signal=USART1_RX
PB8.Signal=I2C1_SCL
PB9.Signal=I2C1_SDA
PC13-TAMPER-RTC.GPIO_Label=ALERT
PC13-TAMPER-RTC.Signal=GPXTI13
PC14-OSC32_IN.GPIO_Label=LED_A
PC14-OSC32_IN.Signal=GPIO_Output
PC15-OSC32_OUT.GPIO_Label=LED_B
PC15-OSC32_OUT.Signal=GPIO_Output
PD0-OSC_IN.Signal=RCC_OSC_IN
PD1-OSC_OUT.Signal=RCC_OSC_OUT

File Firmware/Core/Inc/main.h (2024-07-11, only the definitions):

#define ALERT_Pin GPIO_PIN_13
#define ALERT_GPIO_Port GPIOC
#define ALERT_EXTI_IRQn EXTI15_10_IRQn
#define LED_A_Pin GPIO_PIN_14
#define LED_A_GPIO_Port GPIOC
#define LED_B_Pin GPIO_PIN_15
#define LED_B_GPIO_Port GPIOC
#define KEY_A_Pin GPIO_PIN_9
#define KEY_A_GPIO_Port GPIOA
#define KEY_A_EXTI_IRQn EXTI9_5_IRQn
#define CAN_STB_Pin GPIO_PIN_10
#define CAN_STB_GPIO_Port GPIOA
#define SPI1_NSS_Pin GPIO_PIN_15
#define SPI1_NSS_GPIO_Port GPIOA
#define OLED_DC_Pin GPIO_PIN_4
#define OLED_DC_GPIO_Port GPIOB

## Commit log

2023-12-23 初始化提交
    [BQ76920.kicad_sch, CawBMS-Shell.FCStd, CawBMS.csv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]
2023-12-25 增加过压过流及欠压保护相关配置🛠
2023-12-25 新增获取电池电压功能🔋
2023-12-26 更新目录结构，完善README
    [BQ76920.kicad_sch, CawBMS.csv, CawBMS.kicad_pcb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]
2023-12-27 更新GUI💻
2023-12-30 修复充电MOS无法开启的问题
    [BQ76920.kicad_sch, CawBMS.kicad_pcb]
2023-12-30 调整丝印 📐
    [CawBMS.kicad_pcb, CawBMS.kicad_sch]
2023-12-30 更新README
2023-12-31 更新README（欠压保护）
2024-01-01 移除GUI，优化BQ76920初始化参数，修复电池电压计算🎡
2024-01-06 支持电池组电压监测，支持电流监测，支持充电被动均衡 🥁
2024-01-06 支持关机功能，优化均衡策略 🕹
2024-01-07 生成Gerber文件 🎮
    [CawBMS-B_Cu.gbr, CawBMS-B_Mask.gbr, CawBMS-B_Paste.gbr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]
2024-02-16 支持与CawLink通讯
2024-02-18 支持串口中断接收数据
2024-02-19 支持温度采样
2024-07-11 生成Gerber文件
    [BQ76920.kicad_sch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]
2024-07-11 生成HTML BOM
2025-03-18 kicad版本升级到9.0
    [BQ76920.kicad_sch, CawBMS.kicad_pcb, CawBMS.kicad_sch]

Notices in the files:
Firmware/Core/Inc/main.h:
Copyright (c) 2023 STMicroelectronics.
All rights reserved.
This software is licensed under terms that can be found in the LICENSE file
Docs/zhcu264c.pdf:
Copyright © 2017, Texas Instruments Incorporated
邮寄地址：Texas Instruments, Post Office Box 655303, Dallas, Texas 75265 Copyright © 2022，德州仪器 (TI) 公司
